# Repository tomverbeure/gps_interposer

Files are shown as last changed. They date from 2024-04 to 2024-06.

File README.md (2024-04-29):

* Install PICO SDK

```
export PICO_SDK_PATH="/home/tom/projects/pico-sdk"
```

For DSView:
```
sudo apt install -y qtcreator qtbase5-dev qt5-qmake cmake
```

```
sudo apt install cmake gcc-arm-none-eabi libnewlib-arm-none-eabi libstdc++-arm-none-eabi-newlib
cd ~/projects
git clone git@github.com:raspberrypi/pico-sdk.git
cd pico-sdk
git submodule update --init --recursive
```

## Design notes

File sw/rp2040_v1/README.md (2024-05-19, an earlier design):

# M12 interposer RP2040 firmware.

This first version parsers all the commands that are going from the module
to the S200 and adjust the date by adding 1024 weeks.

It works somewhat, but the date calculation seems wrong (TBD) and
when used with a Furuno GT-8031, it still doesn't make the S200 lock to the
GPS signal.

This version requires commands to arrive fully before they can be patched and
retransmitted. A new version can patch messages as needed on-the-fly.

To build:

* Set the `PICO_SDK_PATH` to your local clone of the [Raspberry pico SDK](https://github.com/raspberrypi/pico-sdk).

    E.g. `export PICO_SDK_PATH=/home/tom/projects/pico-sdk`

* Create `build` directory under the `rp2040_v1` directory
* Build:

```sh
cd build
cmake ..
make
```

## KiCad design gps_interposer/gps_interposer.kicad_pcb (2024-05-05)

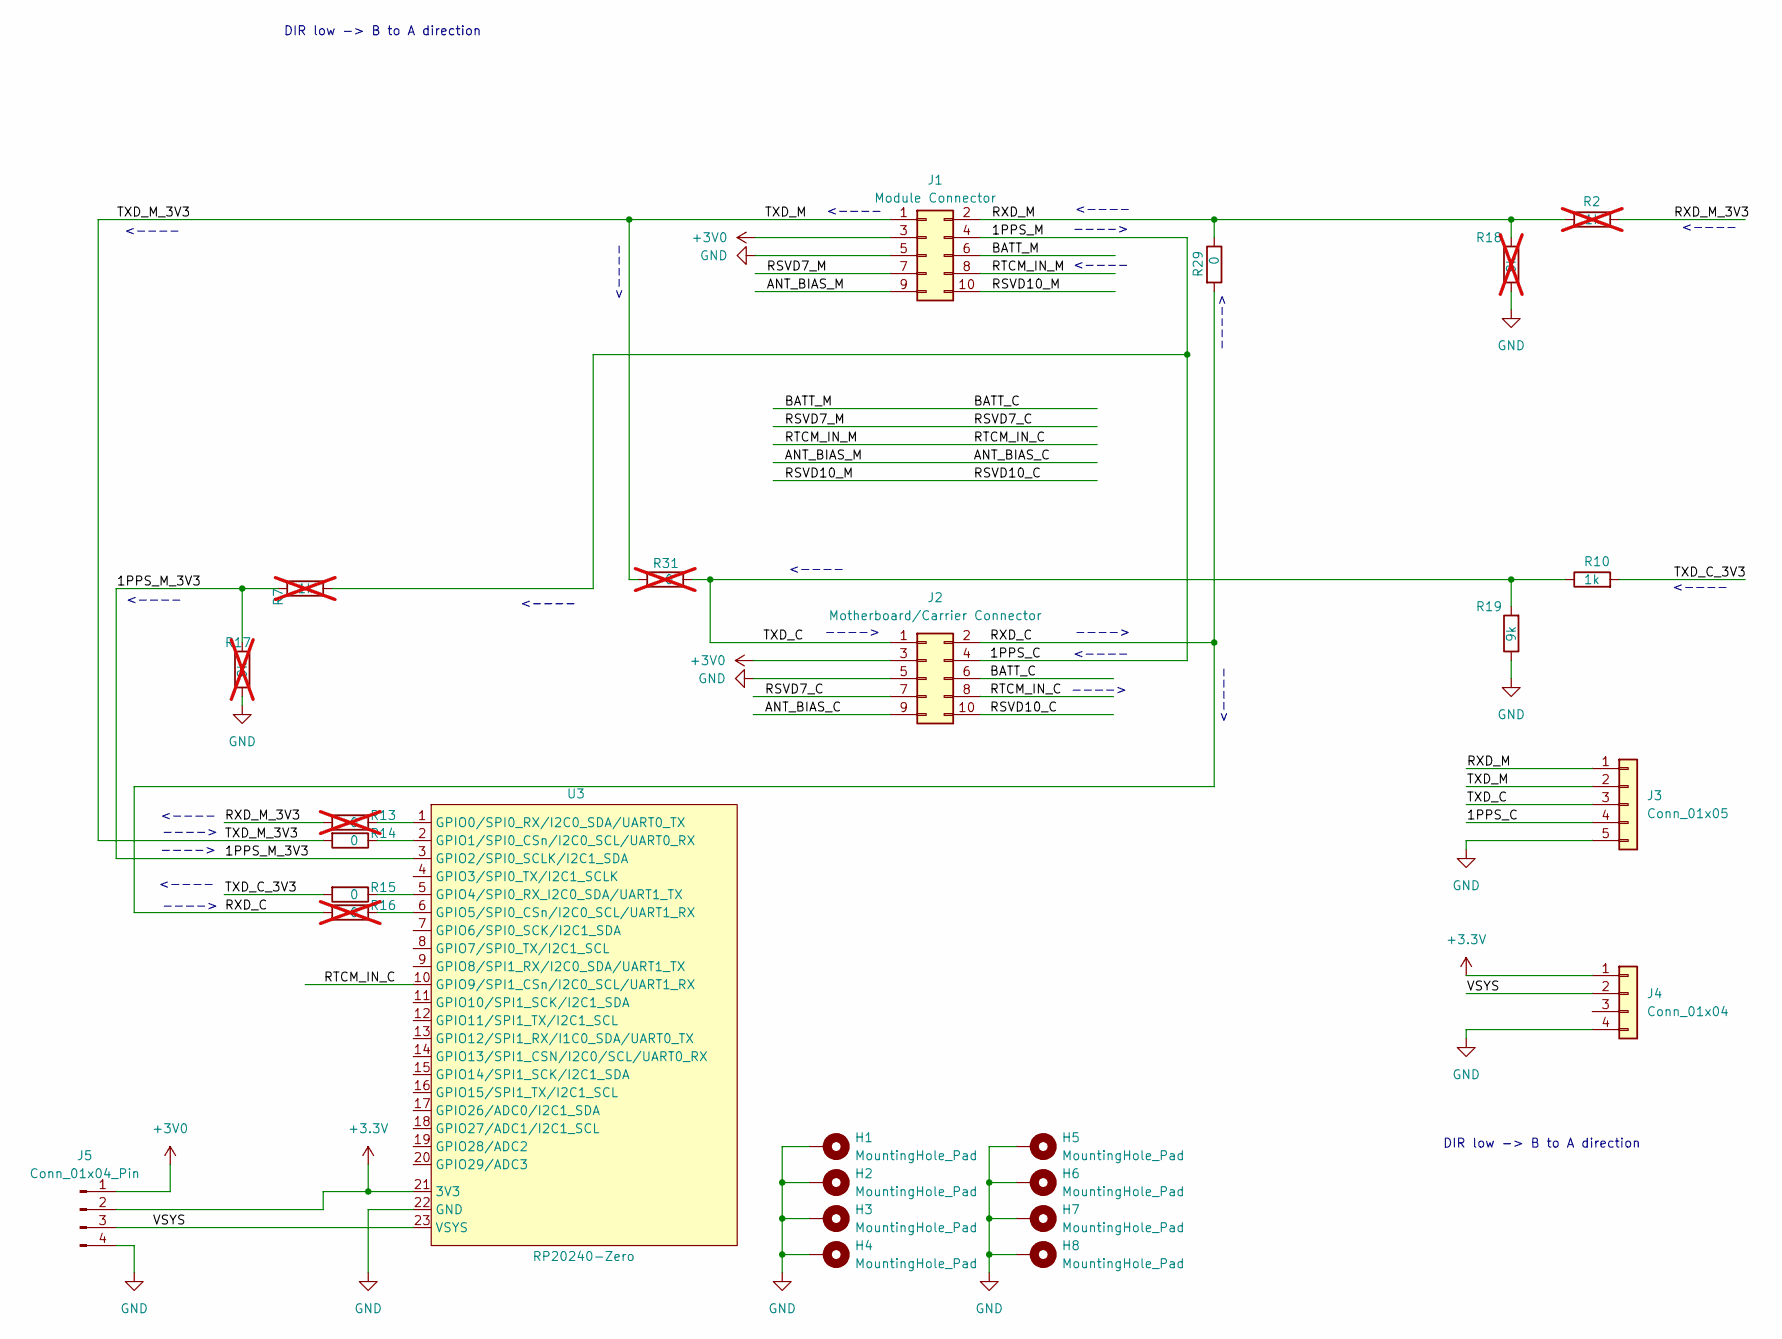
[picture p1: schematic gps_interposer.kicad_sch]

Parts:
H1, H2, H3, H4, H5, H6, H7, H8: MountingHole_Pad; MountingHole_2.5mm_3.9mm_Pad_TopBottom_1
J1: Module Connector; PinSocket_2x05_P1.27mm_Vertical_SMD
J2: Motherboard/Carrier Connector; PinHeader_2x05_P1.27mm_Vertical_SMD
J3: Conn_01x05; PinHeader_1x05_P2.54mm_Vertical_SMD_Pin1Left
J4: Conn_01x04; PinHeader_1x04_P2.54mm_Horizontal
J5: Conn_01x04_Pin; PinHeader_1x04_P2.54mm_Horizontal
R2, R7: 1k; R_0603_1608Metric_Pad0.98x0.95mm_HandSolder; not fitted
R10: 1k; R_0603_1608Metric_Pad0.98x0.95mm_HandSolder
R13, R16, R31: 0; R_0603_1608Metric_Pad0.98x0.95mm_HandSolder; not fitted
R14, R15, R29: 0; R_0603_1608Metric_Pad0.98x0.95mm_HandSolder
R17, R18: 9k; R_0603_1608Metric_Pad0.98x0.95mm_HandSolder; not fitted
R19: 9k; R_0603_1608Metric_Pad0.98x0.95mm_HandSolder
U3: RP20240-Zero; RP2040-Zero

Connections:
+3.3V: J4.1, J5.2, U3.21 (3V3)
+3V0: J1.3, J2.3, J5.1
/1PPS_C: J1.4, J2.4, J3.4, R7.1
/1PPS_M_3V3: R7.2, R17.2, U3.3 (GPIO2/SPI0_SCLK/I2C1_SDA)
/ANT_BIAS_C: J1.9, J2.9
/BATT_C: J1.6, J2.6
/RSVD7_C: J1.7, J2.7
/RSVD10_C: J1.10, J2.10
/RTCM_IN_C: J1.8, J2.8, U3.10 (GPIO9/SPI1_CSn/I2C0_SCL/UART1_RX)
/RXD_C: J2.2, R16.2, R29.2
/RXD_M: J1.2, J3.1, R2.2, R18.2, R29.1
/RXD_M_3V3: R2.1, R13.2
/TXD_C: J2.1, J3.3, R10.1, R19.2, R31.1
/TXD_C_3V3: R10.2, R15.2
/TXD_M: J1.1, J3.2, R14.2, R31.2
/VSYS: J4.2, J5.3, U3.23 (VSYS)
GND: H1.1, H2.1, H3.1, H4.1, H5.1, H6.1, H7.1, H8.1, J1.5, J2.5, J3.5, J4.4, J5.4, R17.1, R18.1, R19.1, U3.22 (GND)
unnamed: R13.1, U3.1 (GPIO0/SPI0_RX/I2C0_SDA/UART0_TX)
unnamed: R14.1, U3.2 (GPIO1/SPI0_CSn/I2C0_SCL/UART0_RX)
unnamed: R15.1, U3.5 (GPIO4/SPI0_RX_I2C0_SDA/UART1_TX)
unnamed: R16.1, U3.6 (GPIO5/SPI0_CSn/I2C0_SCL/UART1_RX)

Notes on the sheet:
<----
---->
DIR low -> B to A direction

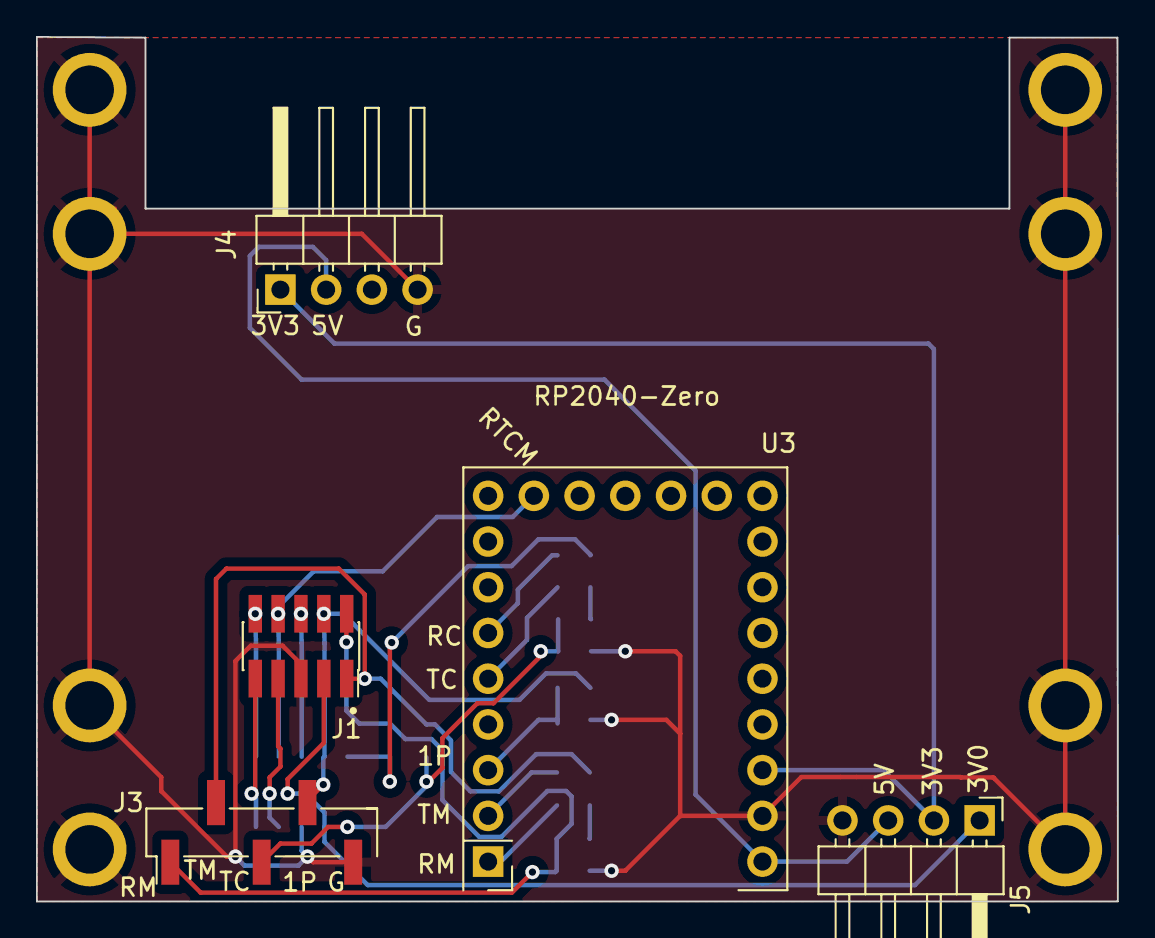
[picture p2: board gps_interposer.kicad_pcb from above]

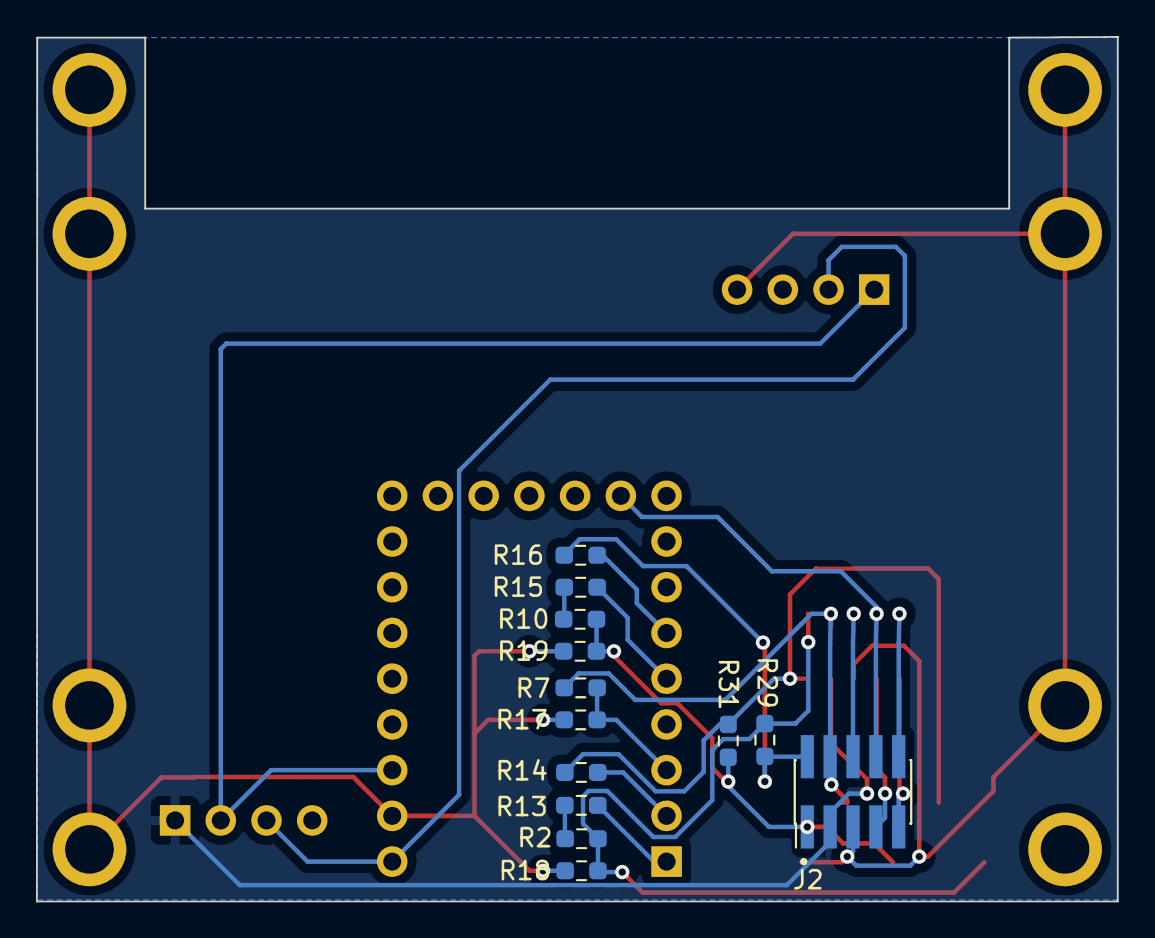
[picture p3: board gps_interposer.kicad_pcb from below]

Board: 2 copper layers, 60.1 x 48.0 mm, 26 parts (13 on the bottom side), 21 nets.

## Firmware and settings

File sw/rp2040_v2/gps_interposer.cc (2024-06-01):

#include <stdio.h>
#include <string.h>
#include <time.h>
#include "pico/stdlib.h"
#include "hardware/uart.h"

// https://github.com/ForsakenNGS/Pico_WS2812
#include "../shared/WS2812.hpp"

#include "../shared/m12_parser.h"

// UART0: module
#define UART0_ID            uart0
#define UART0_TX_PIN        0
#define UART0_RX_PIN        1
#define UART0_BAUD_RATE     9600

// UART1: carrier/motherboard
#define UART1_ID            uart1
#define UART1_TX_PIN        4
#define UART1_RX_PIN        5
#define UART1_BAUD_RATE     9600

#define LED_PIN             16
#define LED_LENGTH          1
#define LED_BLINK_PERIOD_US 1000000

void hw_init()
{
    uart_init(UART0_ID, UART0_BAUD_RATE);
    gpio_set_function(UART0_TX_PIN, GPIO_FUNC_UART);
    gpio_set_function(UART0_RX_PIN, GPIO_FUNC_UART);
    uart_set_hw_flow(UART0_ID, false, false);

    uart_init(UART1_ID, UART1_BAUD_RATE);
    gpio_set_function(UART1_TX_PIN, GPIO_FUNC_UART);
    gpio_set_function(UART1_RX_PIN, GPIO_FUNC_UART);
    uart_set_hw_flow(UART1_ID, false, false);
}

void xmit_msg(uart_inst *uart_id, const char msg[], int len)
{
    printf("xmit_msg: ");
    for(int i=0;i<len;++i){
        printf("%02x ", msg[i]);
        uart_putc(uart_id, msg[i]);
        sleep_us(2000);
    }
    printf("\n");
}

void test_alive()
{
    while(1){
        printf("Hello, world!\n");
        uart_puts(UART0_ID, "Hello world UART0\n");
        uart_puts(UART1_ID, "Hello world UART1\n");
        sleep_ms(1000);
    }
}

typedef struct 
{
    int     wait_us;
    char    data;
} tx_element;

tx_element tx_buf[1024];
int tx_buf_wr_ptr   = 0;
int tx_buf_rd_ptr   = 0;

bool        cur_tx_active = false;
tx_element  cur_tx;

void uart_paced_xmit(int wait_us, char data)
{
    tx_element e;

    e.wait_us   = wait_us;
    e.data      = data;

    tx_buf[tx_buf_wr_ptr] = e;
    tx_buf_wr_ptr   = (tx_buf_wr_ptr + 1) % 1024;
}

int main() {
    stdio_init_all();
    hw_init();

    WS2812 ledStrip(LED_PIN, LED_LENGTH, pio0, 0, WS2812::FORMAT_RGB);

    ledStrip.fill( WS2812::RGB(64, 0, 0) );
    ledStrip.show();

    M12Parser req_parser(true);
    M12Parser resp_parser(false);

    uint64_t    next_led_flip_time_us   = time_us_64() + LED_BLINK_PERIOD_US;
    int         led_state = 1;

    uint64_t    next_uart_tx_time_us    = time_us_64();

    while(true){

        //============================================================
        // Request by carrier
        //===========================================================
        if (uart_is_readable(UART1_ID)){
            char c_from_carrier = uart_getc(UART1_ID);

            next_led_flip_time_us  = time_us_64() + LED_BLINK_PERIOD_US;
            if (led_state != 2){
                ledStrip.fill( WS2812::RGB(0, 64, 0) );
                ledStrip.show();
            }
            led_state   = 2;

            uart_paced_xmit(2000, c_from_carrier);

            bool req_msg_complete = req_parser.parse(c_from_carrier);
            if (req_msg_complete){
                printf("req : %s - %d\n", req_parser.get_msg_id(), req_parser.get_msg_len(req_parser.get_msg_id()) );

                if (strcmp(req_parser.get_msg_id(), "Gd") == 0){
                    printf("Insert Gb...\n");
                    // Insert time correction command
                    char gb_set_msg[]  = { '@',  '@', 'G', 'b', 
                                            5,                                  // month
                                            4,                                  // day
                                            2024>>8, 2024&255,                  // year
                                            0,                                  // hours
                                            0,                                  // minutes
                                            0,                                  // seconds
                                            0,                                  // GMT offset sign
                                            0,                                  // GMT hour offset
                                            0,                                  // GMT minute offset
                                            0,                                  // checksum
                                            0x0d,                               // terminator
                                            0x0a };                             // terminator

                    gb_set_msg[sizeof(gb_set_msg)-3]  = req_parser.calc_checksum(gb_set_msg, 2, 13);

                    for(int i=0;i<sizeof(gb_set_msg);++i){
                        uart_paced_xmit(i==0 ? 50000 : 2000, gb_set_msg[i]);
                    }

                    #if 0
                    char gb_query_msg[]  = { '@',  '@', 'G', 'b', 
                                            0xff,                               // month
                                            0xff,                               // day
                                            0xff, 0xff,                         // year
                                            0xff,                               // hours
                                            0xff,                               // minutes
                                            0xff,                               // seconds
                                            0xff,                               // GMT offset sign
                                            0xff,                               // GMT hour offset
                                            0xff,                               // GMT minute offset
                                            0x25,                               // checksum
                                            0x0d,                               // terminator
                                            0x0a };                             // terminator
                    xmit_msg(UART0_ID, gb_query_msg, sizeof(gb_query_msg));
                    #endif
                }
            }
        }

        if (tx_buf_rd_ptr != tx_buf_wr_ptr || cur_tx_active){
            if (!cur_tx_active){
                cur_tx_active           = true;
                cur_tx                  = tx_buf[tx_buf_rd_ptr];
                tx_buf_rd_ptr           = (tx_buf_rd_ptr + 1) % 1024;

                next_uart_tx_time_us    = time_us_64() + cur_tx.wait_us;
            }
            else if (time_us_64() > next_uart_tx_time_us){
                uart_putc(UART0_ID, cur_tx.data);
                cur_tx_active           = false;
            }
        }

        //============================================================
        // Response by module
        //============================================================
        if (uart_is_readable(UART0_ID)){
            char c_from_module = uart_getc(UART0_ID);
            next_led_flip_time_us  = time_us_64() + LED_BLINK_PERIOD_US;

            if (led_state != 2){
                ledStrip.fill( WS2812::RGB(0, 64, 0) );
                ledStrip.show();
            }
            led_state   = 2;

            uart_putc(UART1_ID, c_from_module);

            bool resp_msg_complete = resp_parser.parse(c_from_module);
            if (resp_msg_complete){
                printf("resp: %s - %d\n", resp_parser.get_msg_id(), resp_parser.get_msg_len(resp_parser.get_msg_id()) );

                if (strcmp(resp_parser.get_msg_id(), "Ha") == 0){
                    struct tm date  = { 0 };

                    // Extract time from packet
                    date.tm_mon     = resp_parser.buf[4] - 1;
                    date.tm_mday    = resp_parser.buf[5];
                    date.tm_year    = (resp_parser.buf[6] * 256) + resp_parser.buf[7] - 1900; // Year since 1900

                    printf("Date: %d/%d/%d\n", date.tm_year + 1900, date.tm_mon+1, date.tm_mday);
                }

            }

        }


        if (time_us_64() > next_led_flip_time_us){
            //printf("%d ", led_state);
            next_led_flip_time_us   += LED_BLINK_PERIOD_US;

            led_state   = led_state ? 0 : 1;
            ledStrip.fill( WS2812::RGB(64 * led_state, 0, 0) );
            ledStrip.show();
            continue;
        }
    }
}

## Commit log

2024-04-08 PCB almost done.
    [gps_interposer.kicad_pcb, gps_interposer.kicad_sch]
2024-04-09 PCB ready.
    [gps_interposer-B_Cu.gbr, gps_interposer-B_Mask.gbr, gps_interposer-B_Paste.gbr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]
2024-04-29 Write to STDIO USB, UART0 and UART1.
2024-05-05 PCB v2.
    [gps_interposer-B_Cu.gbr, gps_interposer-B_Mask.gbr, gps_interposer-B_Paste.gbr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]
2024-05-05 V2 gerbers.
2024-05-05 Fix adding 1024 weeks.
    [gps_interposer.c]
2024-05-05 Additional connectors.
    [gps_interposer-B_Cu.gbr, gps_interposer-B_Mask.gbr, gps_interposer-B_Paste.gbr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]
2024-05-27 Blink LED. Mark correct resistors as installed.
    [gps_interposer.kicad_sch]
2024-05-31 Wire up RX interposer.
    [gps_interposer.kicad_sch]
